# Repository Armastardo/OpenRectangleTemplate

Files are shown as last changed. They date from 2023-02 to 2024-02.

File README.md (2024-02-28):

# Open Rectangle Template
**RP2040 template for use with box style controllers for the GC**

<p align="center">
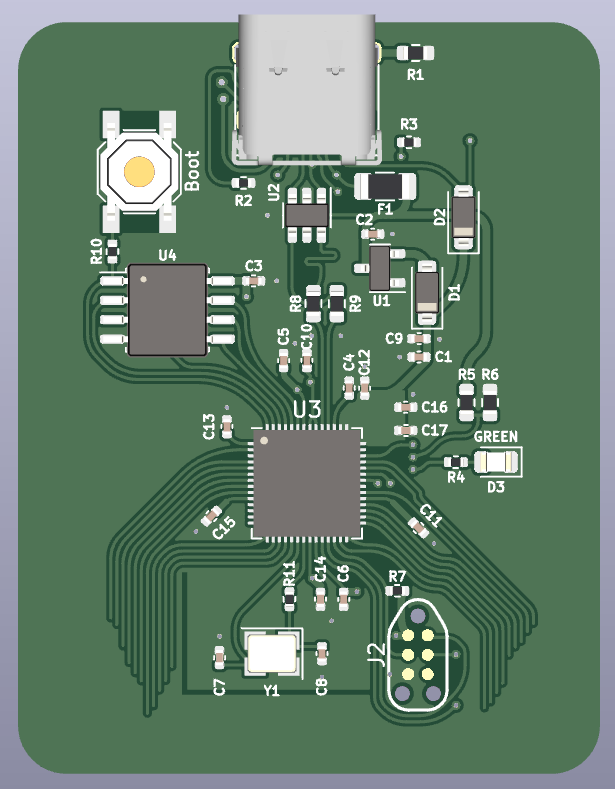
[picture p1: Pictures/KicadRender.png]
  
</p>

## Table of contents
* [About](#about)
* [Usage](#usage)
* [Featured projects](#projects)
* [To-do](#to-do)
* [Acknowledgements](#acknowledgements)

## About
This template was created for the purpose of easing development of box-styled controllers (rectangles) that work with a GameCube console and Nintendo 64 via a USB C to console cable. It uses a RP2040 as its main controller so compatibility to other devices will be limited to the firmware you are using. (Such as [HayBox](https://github.com/JonnyHaystack/HayBox), [Pico-Rectangle](https://github.com/JulienBernard3383279/pico-rectangle), etc). There's already a footprint added for a compatible USB-C port that will allow you to used said cables, as well as a USB C to C cable, or C to A cable for PC or Switch.

Labels are already assigned to the default pinout of the most popular firmware available as well as in stock parts for every component from LCSC. I recommend using the Fabrication Toolkit plugin that can be installed through KiCad's PCM.

## Usage
This templates requires for you to have a minium experience with Kicad and some EE basics. You can just download it as .zip and start creating your own. Make sure you are using **Kicad 7**.
- Download as a zip or clone the repository.
- Open KiCad (7 or newer!) and go to File -> New Project from Template
- Select the tab "User Templates" and click on the Folder icon top right.
- Look for the directory where the kicad project is and open it.
- Template should load. Just click OK and everything will be imported into your project.

## To-do:
- Write a more extensive guide.
- Feature more projects.

## Projects
Small section to highlight proyects that were devveloped using this template.
- [Open Rectangle Breakout](https://github.com/Armastardo/OpenRectangleBreakout) - Breakout board designed to make handwired builds easier.

## Acknowledgements:
- [@Sleepdealr](https://github.com/Sleepdealr/) - For creating the [RP2040 design guide](https://github.com/Sleepdealr/RP2040-designguide) which this template is mostly based from
- Crane's Lab - For having such an amazing community and inspiring creativity in everyone who steps there.
- [@rana-sylvatica](https://github.com/rana-sylvatica/) - For making the OFOF1/Rana Digital and inspiring me to design my rectangles.
- [@Ryanemzed](https://github.com/Ryanemzed/) - For posting a cool clear acrylic build and taking me into a new rabbit hole (and being an amazing community member!).
- The Phob project - For being an amazing standard for the open source-community.

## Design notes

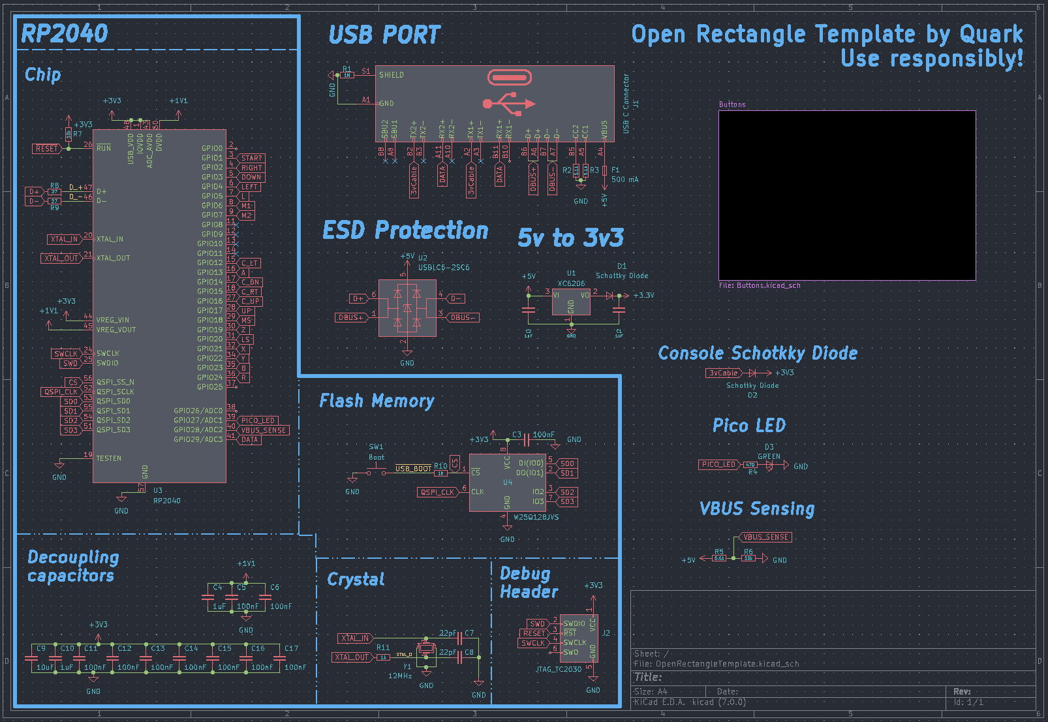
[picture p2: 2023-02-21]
Pictures/Schematic.png

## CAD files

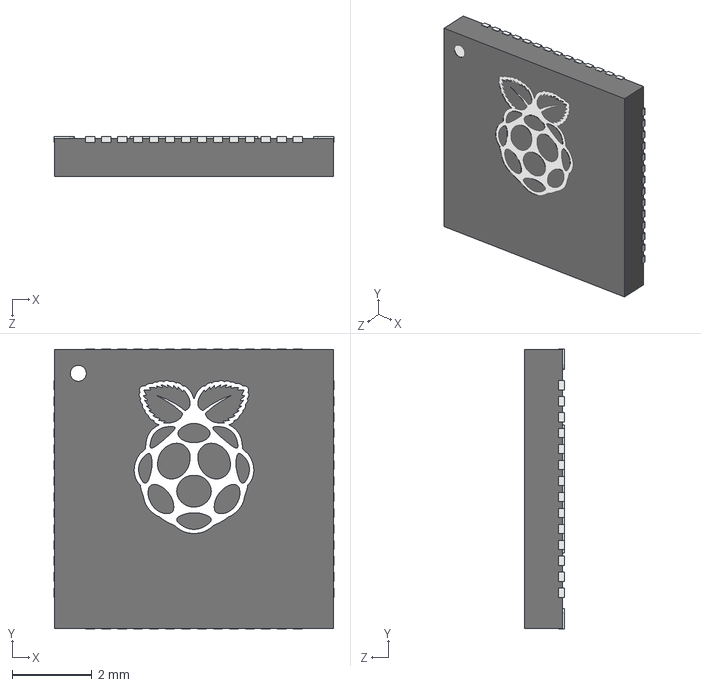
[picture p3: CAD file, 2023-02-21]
model/RP2040_QFN_PACKAGE.STEP
7.02 x 7.02 x 1.00 mm

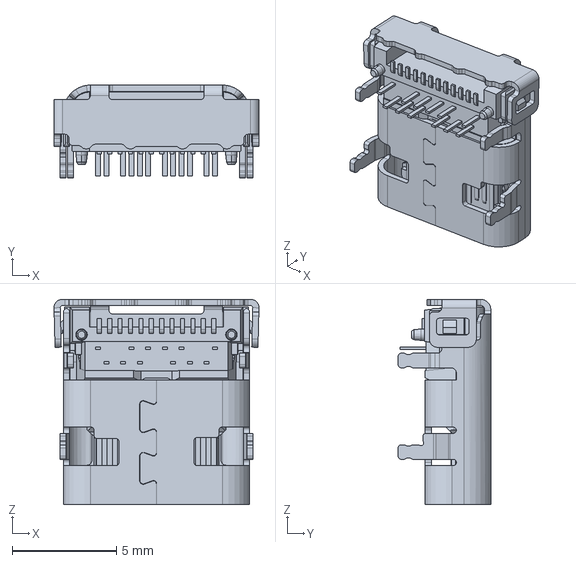
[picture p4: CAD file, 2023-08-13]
model/2171830001.stp
9.85 x 4.46 x 9.87 mm

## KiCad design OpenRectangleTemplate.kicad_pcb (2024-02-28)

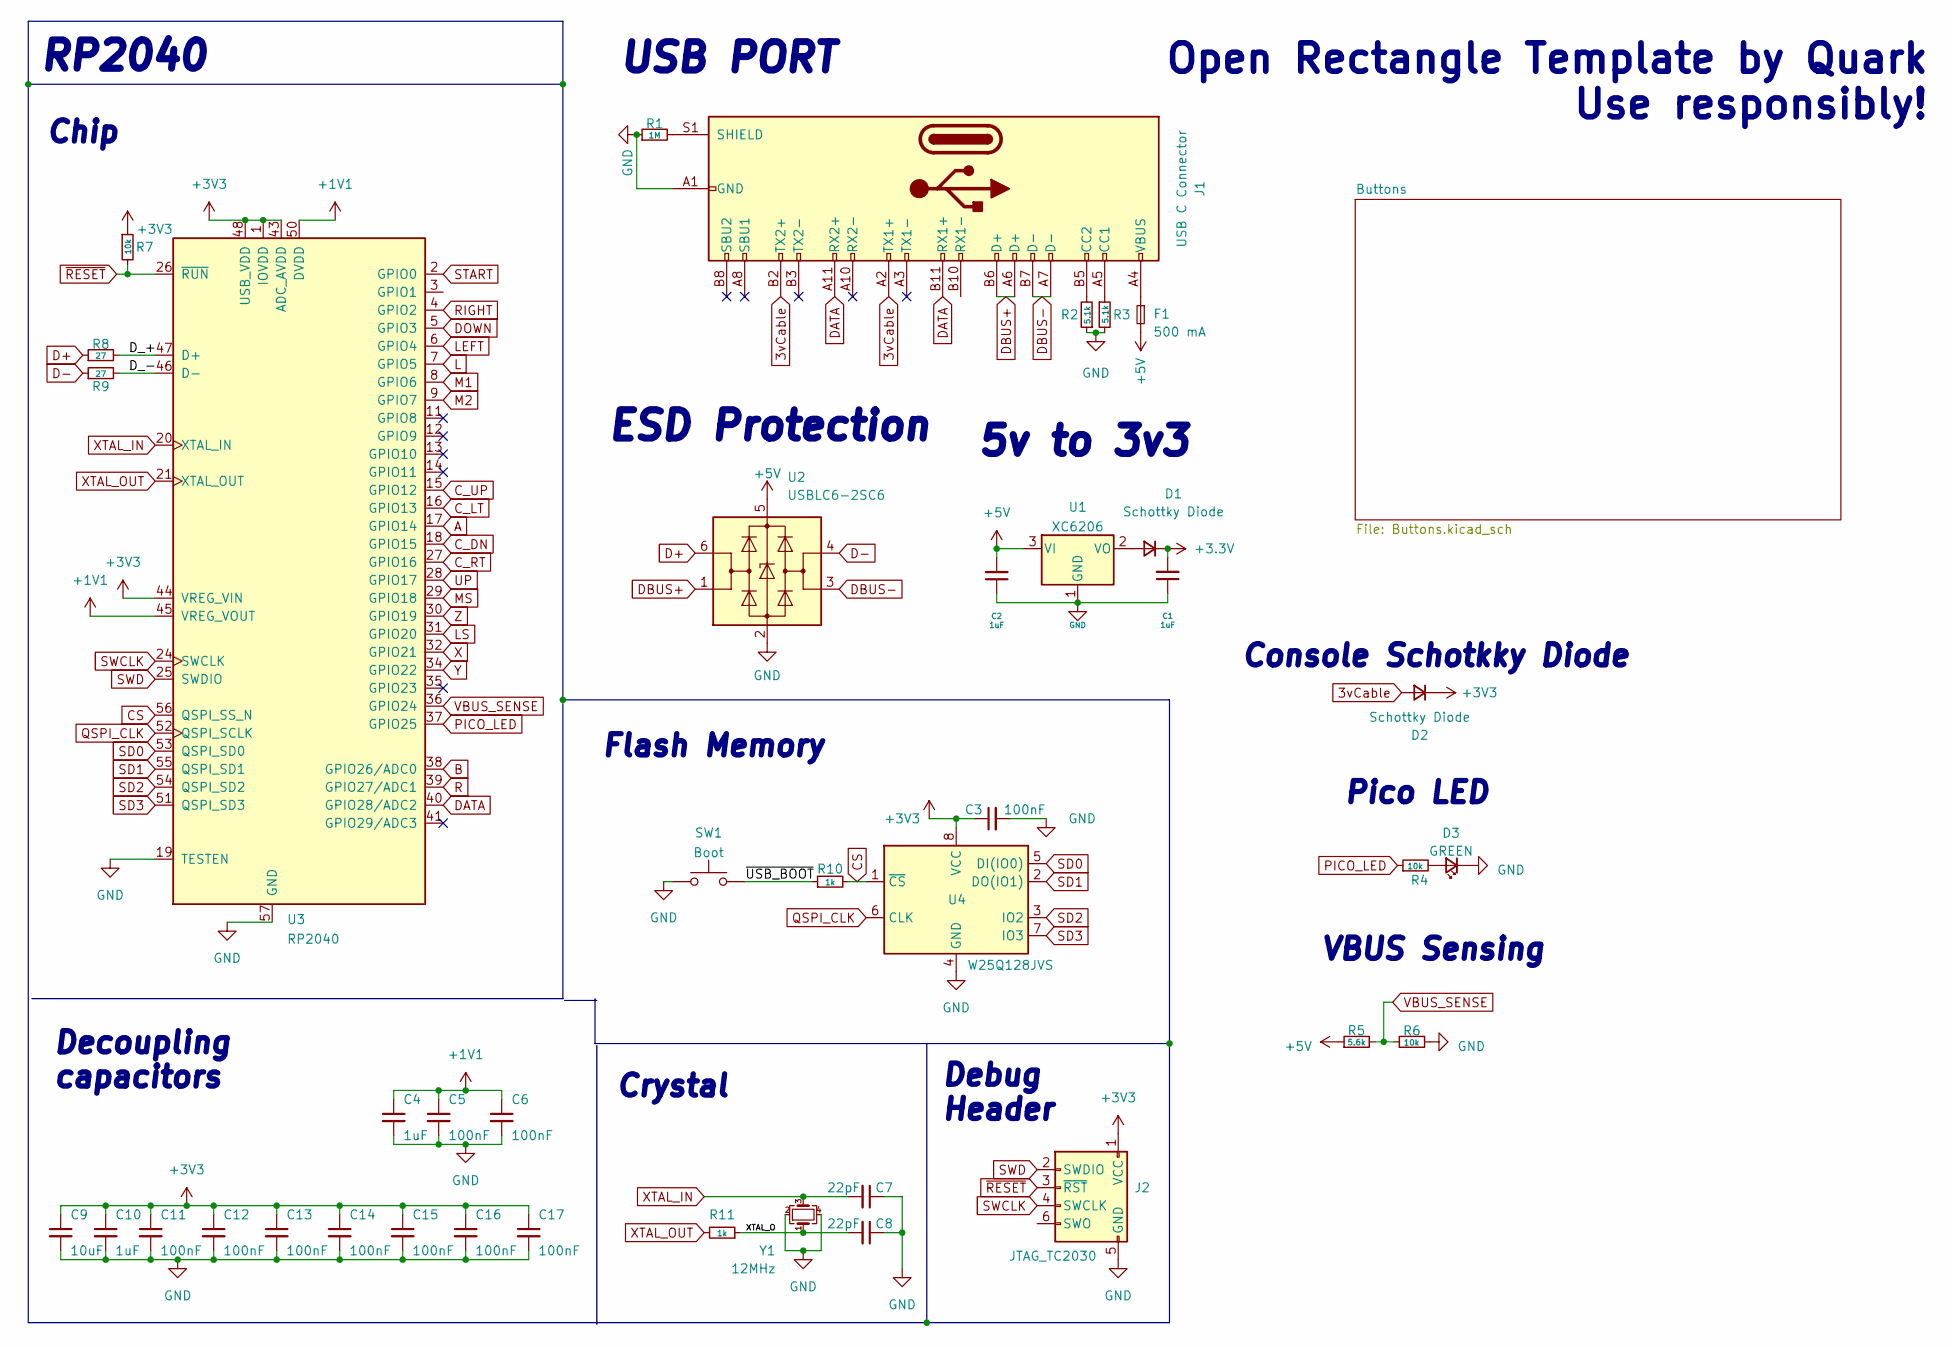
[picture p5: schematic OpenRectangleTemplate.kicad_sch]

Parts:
C1, C2, C4, C10: 1uF; C_0402_1005Metric; LCSC C52923
C3, C5, C6, C11, C12, C13, C14, C15, C16, C17: 100nF; C_0402_1005Metric; LCSC C1525
C7, C8: 22pF; C_0402_1005Metric; LCSC C1555
C9: 10uF; C_0402_1005Metric; LCSC C15525
D1, D2: Schottky Diode; D_SOD-123; LCSC C8598
D3: GREEN; LED_0805_2012Metric; LCSC C2297
F1: 500 mA; Fuse_1206_3216Metric; LCSC C70076
J1: USB C Connector; TYPE-C_24P_QCHT; LCSC C456013
J2: JTAG_TC2030; CON_TC2030_outlined
R1: 1M; R_0603_1608Metric; LCSC C22935
R2, R3: 5.1k; R_0402_1005Metric; LCSC C25905
R4, R7: 10k; R_0402_1005Metric; LCSC C25744
R5: 5.6k; R_0603_1608Metric; LCSC C23189
R6: 10k; R_0603_1608Metric; LCSC C25804
R8, R9: 27; R_0603_1608Metric; LCSC C25190
R10, R11: 1k; R_0402_1005Metric; LCSC C11702
SW1: Boot; SW_SPST_SKQG_WithStem; LCSC C318884
U1: XC6206; SOT-23; LCSC C5446
U2: USBLC6-2SC6; SOT-23-6; LCSC C7519
U3: RP2040; RP2040-QFN-56; LCSC C2040
U4: W25Q128JVS; SOIC-8_5.23x5.23mm_P1.27mm; LCSC C97521
Y1: 12MHz; Crystal_SMD_3225-4Pin_3.2x2.5mm; LCSC C9002

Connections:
3vCable: D2.2 (A), J1.A2 (TX1+), J1.B2 (TX2+)
+1V1: C4.1, C5.1, C6.1, U3.23 (DVDD), U3.45 (VREG_VOUT), U3.50 (DVDD)
+5V: C2.2, F1.2, R5.1, U1.3 (VI), U2.5 (VBUS)
/D_+: R8.2, U3.47 (D+)
/D_-: R9.2, U3.46 (D-)
/XTAL_O: C8.2, R11.1, Y1.1
/~USB_BOOT: R10.1, SW1.2
A: U3.17 (GPIO14)
B: U3.38 (GPIO26/ADC0)
CS: R10.2, U3.56 (QSPI_SS_N), U4.1 (~CS)
C_DN: U3.18 (GPIO15)
C_LT: U3.16 (GPIO13)
C_RT: U3.27 (GPIO16)
C_UP: U3.15 (GPIO12)
D+: R8.1, U2.6 (I/O1)
D-: R9.1, U2.4 (I/O2)
DATA: J1.A11 (RX2+), J1.B11 (RX1+), U3.40 (GPIO28/ADC2)
DBUS+: J1.A6 (D+), J1.B6 (D+), U2.1 (I/O1)
DBUS-: J1.A7 (D-), J1.B7 (D-), U2.3 (I/O2)
DOWN: U3.5 (GPIO3)
GND: C1.1, C2.1, C3.2, C4.2, C5.2, C6.2, C7.1, C8.1, C9.2, C10.2, C11.2, C12.2, C13.2, C14.2, C15.2, C16.2, C17.2, D3.1 (K), J1.A1 (GND), J1.A12 (GND), J1.B1 (GND), J1.B12 (GND), J2.5 (GND), R1.1, R2.1, R3.2, R6.2, SW1.1, U1.1 (GND), U2.2 (GND), U3.19 (TESTEN), U3.57 (GND), U4.4 (GND), Y1.2, Y1.4
L: U3.7 (GPIO5)
LEFT: U3.6 (GPIO4)
LS: U3.31 (GPIO20)
M1: U3.8 (GPIO6)
M2: U3.9 (GPIO7)
MS: U3.29 (GPIO18)
unnamed: D1.2 (A), U1.2 (VO)
unnamed: D3.2 (A), R4.2
unnamed: F1.1, J1.A4 (VBUS), J1.A9 (VBUS), J1.B4 (VBUS), J1.B9 (VBUS)
unnamed: J1.A5 (CC1), R3.1
unnamed: J1.B5 (CC2), R2.2
unnamed: J1.S1 (SHIELD), R1.2
PICO_LED: R4.1, U3.37 (GPIO25)
QSPI_CLK: U3.52 (QSPI_SCLK), U4.6 (CLK)
R: U3.39 (GPIO27/ADC1)
RIGHT: U3.4 (GPIO2)
SD0: U3.53 (QSPI_SD0), U4.5 (DI(IO0))
SD1: U3.55 (QSPI_SD1), U4.2 (DO(IO1))
SD2: U3.54 (QSPI_SD2), U4.3 (IO2)
SD3: U3.51 (QSPI_SD3), U4.7 (IO3)
START: U3.2 (GPIO0)
SWCLK: J2.4 (SWCLK), U3.24 (SWCLK)
SWD: J2.2 (SWDIO), U3.25 (SWDIO)
UP: U3.28 (GPIO17)
VBUS_SENSE: R5.2, R6.1, U3.36 (GPIO24)
X: U3.32 (GPIO21)
XTAL_IN: C7.2, U3.20 (XTAL_IN), Y1.3
XTAL_OUT: R11.2, U3.21 (XTAL_OUT)
Y: U3.34 (GPIO22)
Z: U3.30 (GPIO19)
~RESET: J2.3 (~RST), R7.2, U3.26 (~RUN)

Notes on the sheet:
Console Schotkky Diode
Crystal
USB PORT
Flash Memory
Pico LED
Open Rectangle Template by Quark Use responsibly!
RP2040
Debug Header
VBUS Sensing
Chip
5v to 3v3
ESD Protection
Decoupling capacitors

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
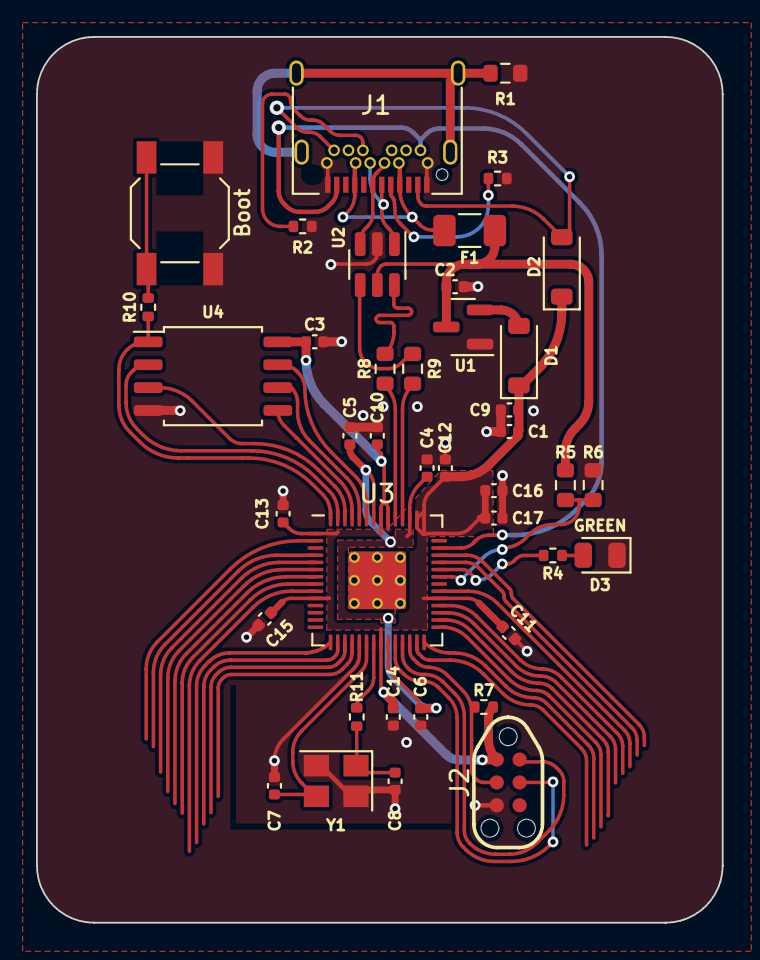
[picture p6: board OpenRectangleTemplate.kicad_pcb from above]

Board: 2 copper layers, 38.1 x 49.2 mm, 40 parts (0 on the bottom side), 33 nets.

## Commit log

2023-02-21 Updated pictures, added schematic
2023-02-21 Reverted back to pico pinout
    [OpenRectangleTemplate.kicad_pcb, OpenRectangleTemplate.kicad_sch]
2023-02-21 Updated render and small changes
    [OpenRectangleTemplate.kicad_pcb]
2023-03-23 Prototyped and tested
    [OpenRectangleTemplate.kicad_pcb, OpenRectangleTemplate.kicad_sch]
2023-07-24 Adjusted the schematic to the correct grid
    [OpenRectangleTemplate.kicad_sch]
2023-08-13 Adjusted part numbers
    [OpenRectangleTemplate.kicad_pcb, OpenRectangleTemplate.kicad_sch]
2023-08-13 Updated 3D models and footprints
    [2171830001.stp, OpenRectangleTemplate.kicad_pcb, OpenRectangleTemplate.kicad_sch]
2024-02-28 Actually a template now
    [OpenRectangleTemplate.kicad_pcb, OpenRectangleTemplate.kicad_sch]
